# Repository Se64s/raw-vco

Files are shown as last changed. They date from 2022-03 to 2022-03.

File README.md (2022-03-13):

# raw-vco

Eurorack VCO module based in EDU DIY VCO from erica synth and Moritz Klein.

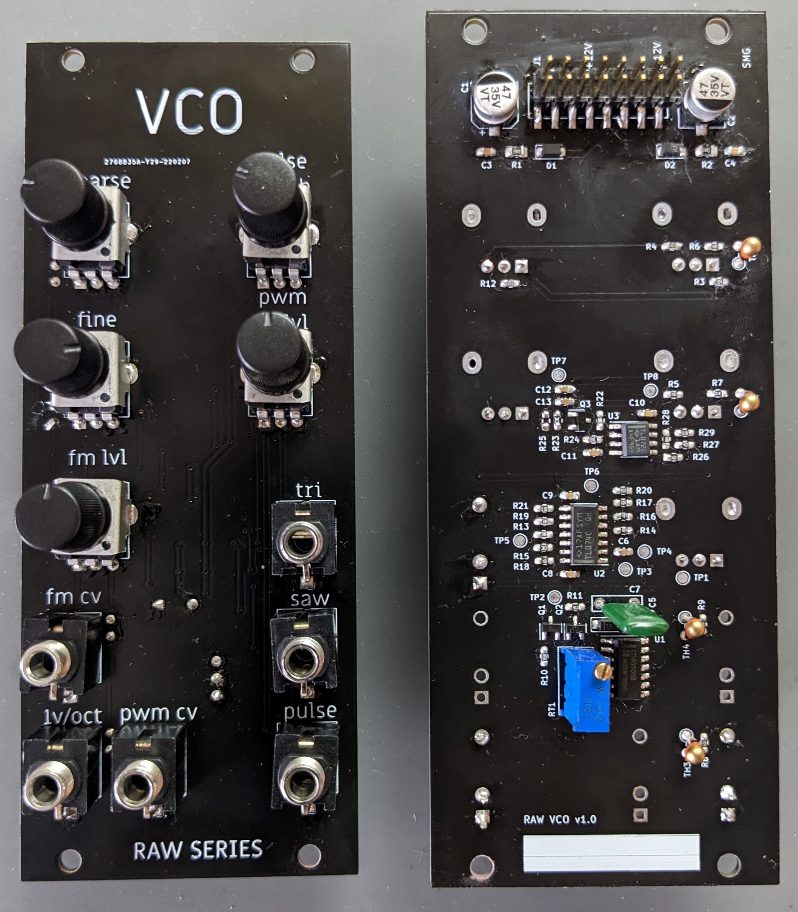
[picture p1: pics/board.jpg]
raw_vco_pcb


# About the project

This is the first module of the series 'RAW'.

The RAW concept is my way to ease access to the modular world, reducing the cost of the modules to the minimum, removing all unnecessary parts without scarify functionality.

In this case, I took the awesome design of Moritz, but I removed the fancy faceplate and I added a saw-triangle converter to have all the basic waveforms.

# Module overview

## Inputs

- lineal fm cv input.
- pwm cv control input.
- 1v/oct control input (good tracking over 5 octaves).

## Outputs

### Triagle
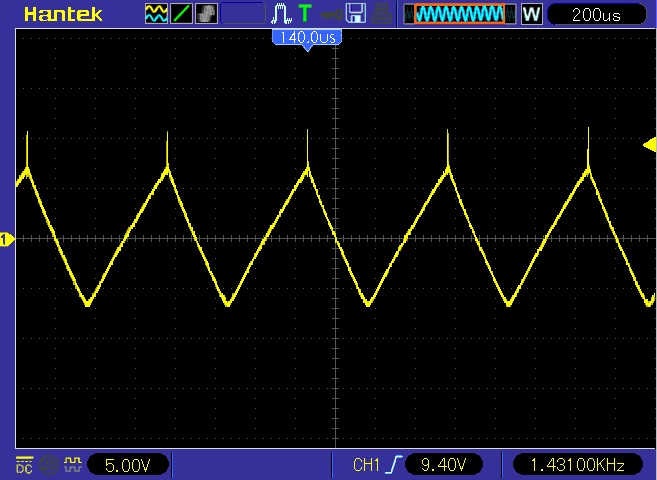
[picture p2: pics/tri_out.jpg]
tri_out


### Saw
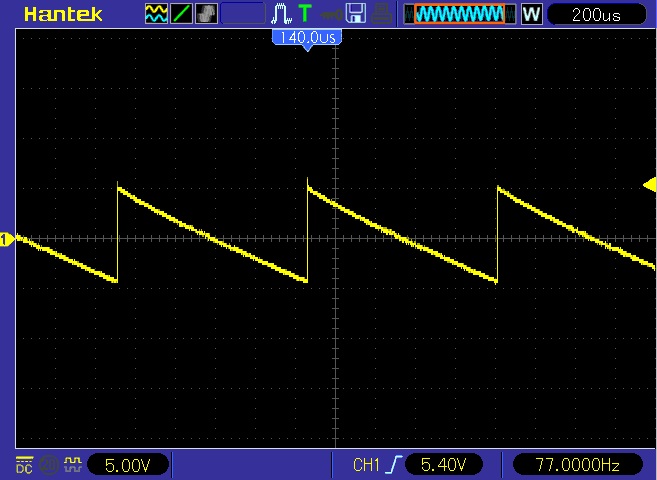
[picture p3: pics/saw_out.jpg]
saw_out


### Square
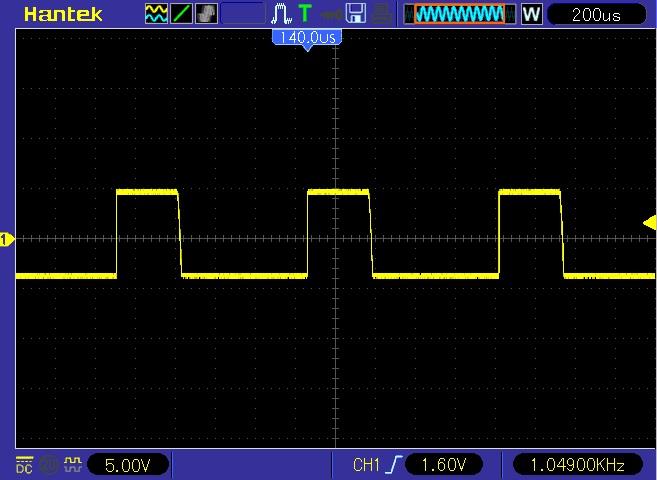
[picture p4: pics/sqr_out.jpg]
sqr_out


# Acknowledgments

All design and guts of this module were done by Moritz Klein so I recommend visiting his awesome videos to get a precise idea of how this module works.

- [mki x es.EDU](https://www.ericasynths.lv/news/mki-x-esedu/)

# Contact

Any feedback is welcome!
- Sebastián Del Moral - sebmorgal@gmail.com

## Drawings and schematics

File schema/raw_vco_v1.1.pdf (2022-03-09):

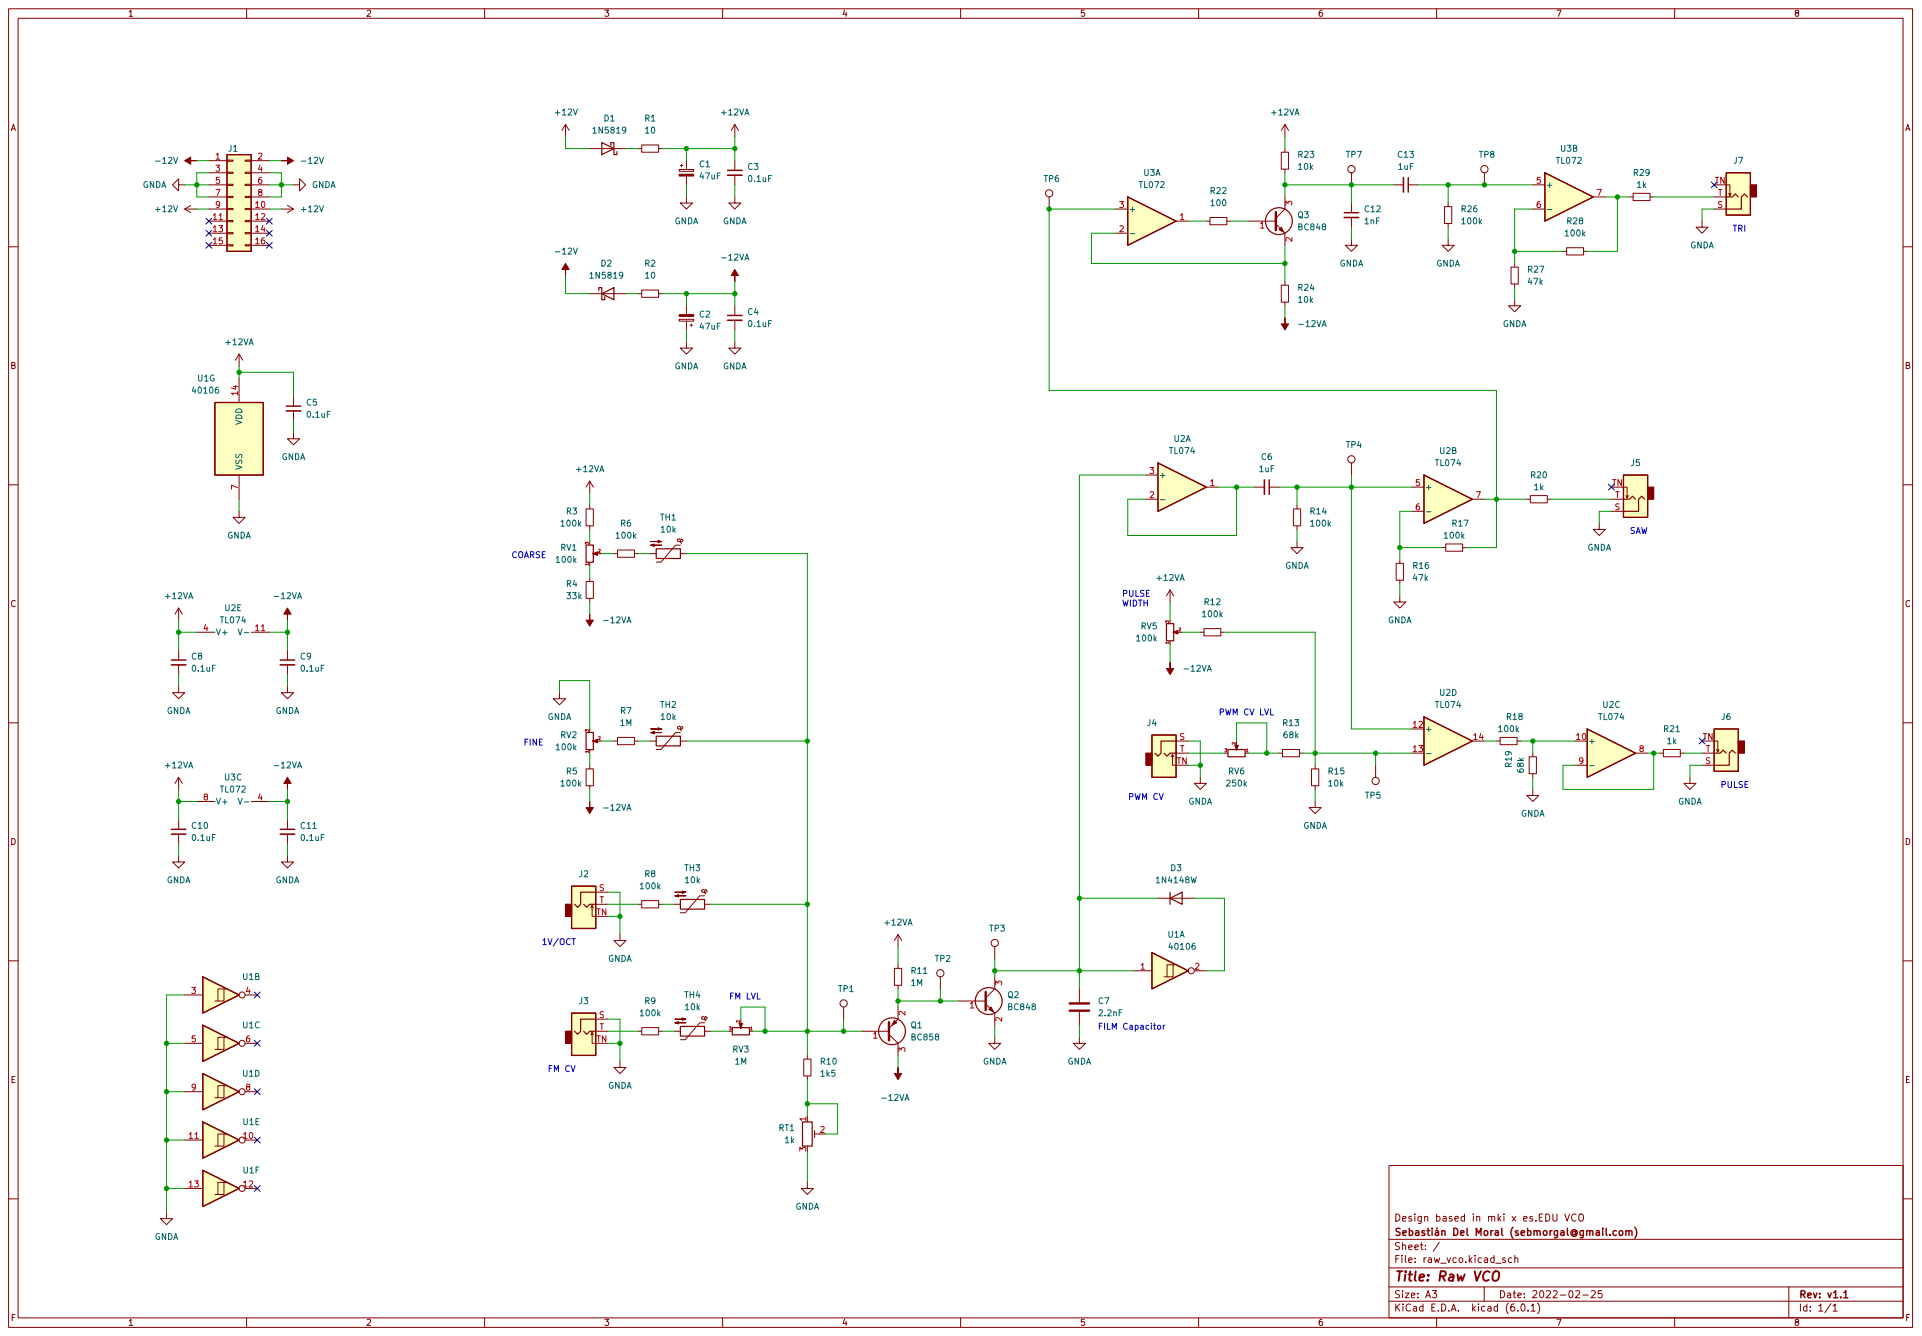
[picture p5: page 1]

PWM CV LVL COARSE

Design based in mki x es.EDU VCO R19 68k

Id: 1/1 Title: Raw VCO

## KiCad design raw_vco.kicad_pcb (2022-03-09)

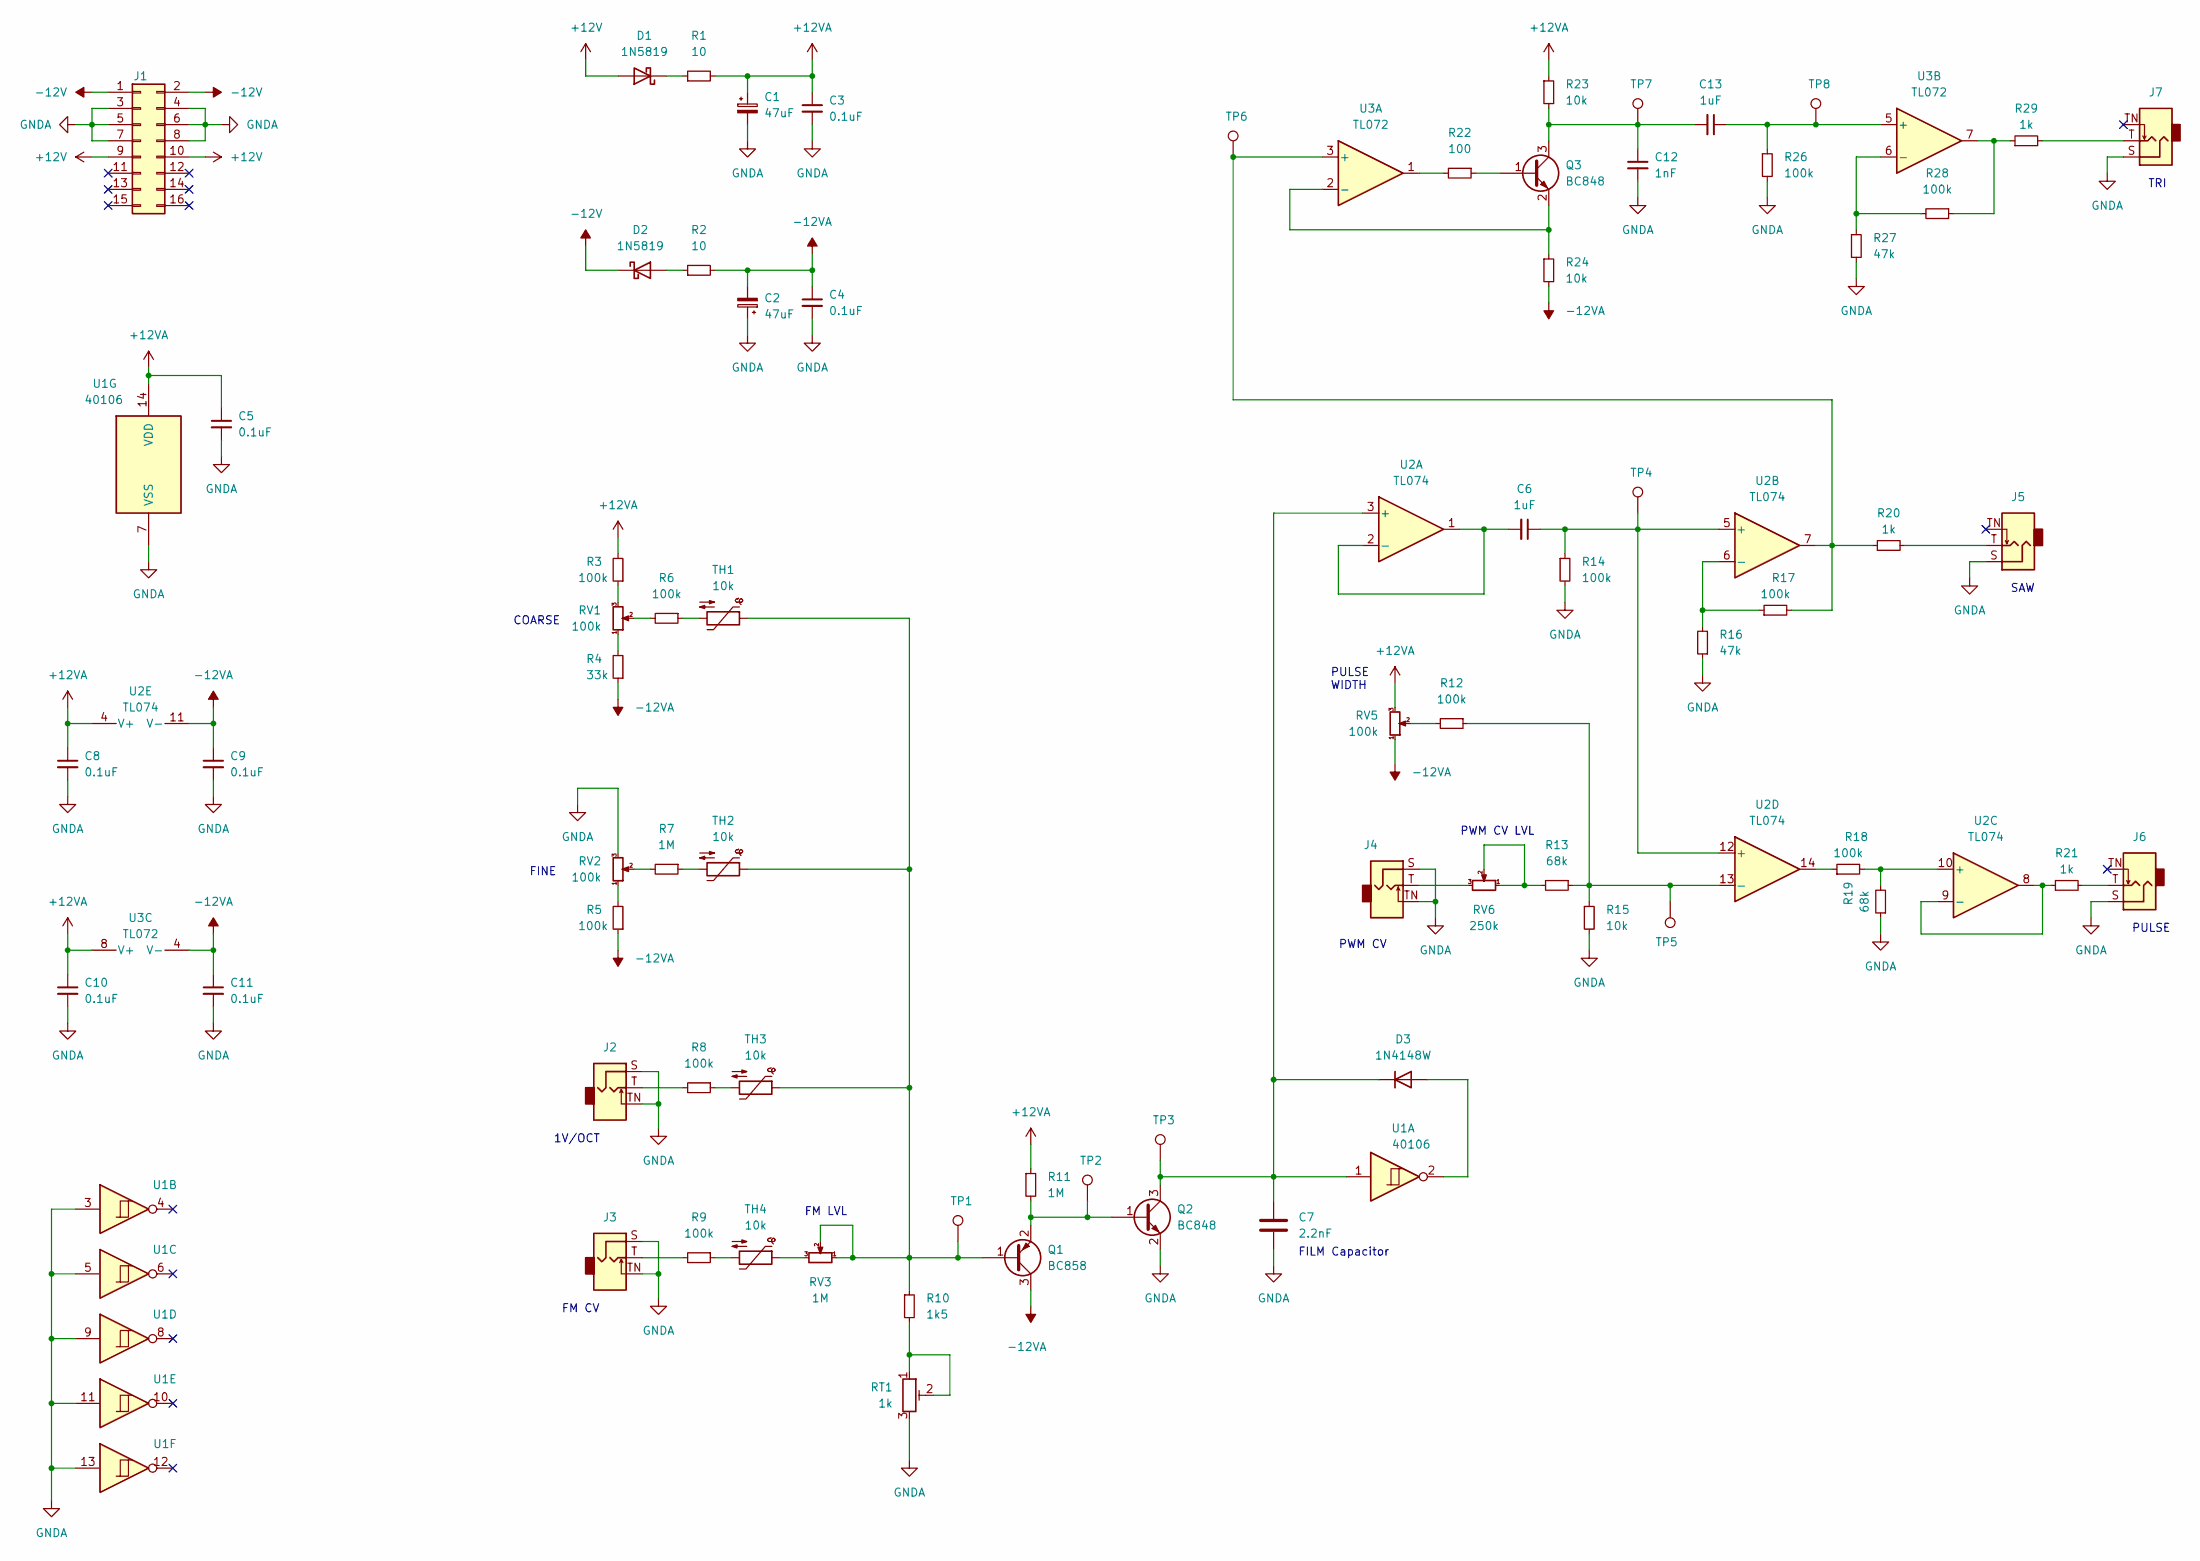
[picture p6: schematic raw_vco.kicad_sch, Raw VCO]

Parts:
C1, C2: 47uF; CP_Elec_6.3x5.4
C3, C4, C5, C8, C9, C10, C11: 0.1uF; C_0603_1608Metric_Pad1.08x0.95mm_HandSolder
C6, C13: 1uF; C_0603_1608Metric_Pad1.08x0.95mm_HandSolder
C7: 2.2nF; C_Rect_L7.0mm_W2.0mm_P5.00mm
C12: 1nF; C_0603_1608Metric_Pad1.08x0.95mm_HandSolder
D1, D2: 1N5819; D_SOD-123
D3: 1N4148W; D_SOD-123
J1: Conn_02x08_Odd_Even; PinHeader_2x08_P2.54mm_Vertical_SMD
J2, J3, J4, J5, J6, J7: AudioJack2_SwitchT; Jack_3.5mm_QingPu_WQP-PJ398SM_Vertical_CircularHoles
Q1: BC858; SOT-23
Q2, Q3: BC848; SOT-23
R1, R2: 10; R_0805_2012Metric_Pad1.20x1.40mm_HandSolder
R3, R5, R6, R8, R9, R12, R14, R17, R18, R26, R28: 100k; R_0603_1608Metric_Pad0.98x0.95mm_HandSolder
R4: 33k; R_0603_1608Metric_Pad0.98x0.95mm_HandSolder
R7, R11: 1M; R_0603_1608Metric_Pad0.98x0.95mm_HandSolder
R10: 1k5; R_0603_1608Metric_Pad0.98x0.95mm_HandSolder
R13, R19: 68k; R_0603_1608Metric_Pad0.98x0.95mm_HandSolder
R15, R23, R24: 10k; R_0603_1608Metric_Pad0.98x0.95mm_HandSolder
R16, R27: 47k; R_0603_1608Metric_Pad0.98x0.95mm_HandSolder
R20, R21, R29: 1k; R_0603_1608Metric_Pad0.98x0.95mm_HandSolder
R22: 100; R_0603_1608Metric_Pad0.98x0.95mm_HandSolder
RT1: 1k; Potentiometer_Bourns_3296W_Vertical
RV1, RV2, RV5: 100k; Potentiometer_Alpha_RD901F-40-00D_Single_Vertical
RV3: 1M; Potentiometer_Alpha_RD901F-40-00D_Single_Vertical
RV6: 250k; Potentiometer_Alpha_RD901F-40-00D_Single_Vertical
TH1, TH2, TH3, TH4: 10k; R_Axial_DIN0204_L3.6mm_D1.6mm_P2.54mm_Vertical
TP1, TP2, TP3, TP4, TP5, TP6, TP7, TP8: TestPoint; TestPoint_Pad_D1.5mm
U1: 40106; SOIC-14_3.9x8.7mm_P1.27mm
U2: TL074; SOIC-14_3.9x8.7mm_P1.27mm
U3: TL072; SOIC-8_3.9x4.9mm_P1.27mm

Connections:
+12V: D1.2 (A), J1.9, J1.10
+12VA: C1.1, C3.1, C5.1, C8.1, C10.1, R1.2, R3.2, R11.1, R23.1, RV5.3, U1.14 (VDD), U2.4 (V+), U3.8 (V+)
-12V: D2.1 (K), J1.1, J1.2
-12VA: C2.2, C4.1, C9.1, C11.1, Q1.3 (C), R2.2, R4.1, R5.1, R24.2, RV5.1, U2.11 (V-), U3.4 (V-)
GNDA: C1.2, C2.1, C3.2, C4.2, C5.2, C7.2, C8.2, C9.2, C10.2, C11.2, C12.2, J1.3, J1.4, J1.5, J1.6, J1.7, J1.8, J2.S, J2.TN, J3.S, J3.TN, J4.S, J4.TN, J5.S, J6.S, J7.S, Q2.2 (E), R14.2, R15.2, R16.1, R19.1, R26.2, R27.2, RT1.3, RV2.3, U1.3, U1.5, U1.7 (VSS), U1.9, U1.11, U1.13
unnamed: C6.1, R14.1, TP4.1, U2.5 (+), U2.12 (+)
unnamed: C6.2, U2.1, U2.2 (-)
unnamed: C7.1, D3.1 (K), Q2.3 (C), TP3.1, U1.1, U2.3 (+)
unnamed: C12.1, C13.2, Q3.3 (C), R23.2, TP7.1
unnamed: C13.1, R26.1, TP8.1, U3.5 (+)
unnamed: D1.1 (K), R1.1
unnamed: D2.2 (A), R2.1
unnamed: D3.2 (A), U1.2
unnamed: J2.T, R8.2
unnamed: J3.T, R9.2
unnamed: J4.T, RV6.3
unnamed: J5.T, R20.2
unnamed: J6.T, R21.2
unnamed: J7.T, R29.2
unnamed: Q1.1 (B), R10.1, RV3.1, RV3.2, TH1.1, TH2.1, TH3.1, TP1.1
unnamed: Q1.2 (E), Q2.1 (B), R11.2, TP2.1
unnamed: Q3.1 (B), R22.1
unnamed: Q3.2 (E), R24.1, U3.2 (-)
unnamed: R3.1, RV1.3
unnamed: R4.2, RV1.1
unnamed: R5.2, RV2.1
unnamed: R6.1, TH1.2
unnamed: R7.1, TH2.2
unnamed: R7.2, RV2.2
unnamed: R8.1, TH3.2
unnamed: R9.1, TH4.2
unnamed: R10.2, RT1.1, RT1.2
unnamed: R12.1, R13.1, R15.1, TP5.1, U2.13 (-)
unnamed: R12.2, RV5.2
unnamed: R13.2, RV6.1, RV6.2
unnamed: R16.2, R17.1, U2.6 (-)
unnamed: R17.2, R20.1, TP6.1, U2.7, U3.3 (+)
unnamed: R18.1, U2.14
unnamed: R18.2, R19.2, U2.10 (+)
unnamed: R21.1, U2.8, U2.9 (-)
unnamed: R22.2, U3.1
unnamed: R27.1, R28.2, U3.6 (-)
unnamed: R28.1, R29.1, U3.7
unnamed: R6.2, RV1.2
unnamed: RV3.3, TH4.1

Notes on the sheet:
FILM Capacitor
PWM CV
TRI
COARSE
PWM CV LVL
FINE
SAW
PULSE
1V/OCT
FM LVL
FM CV
PULSE WIDTH

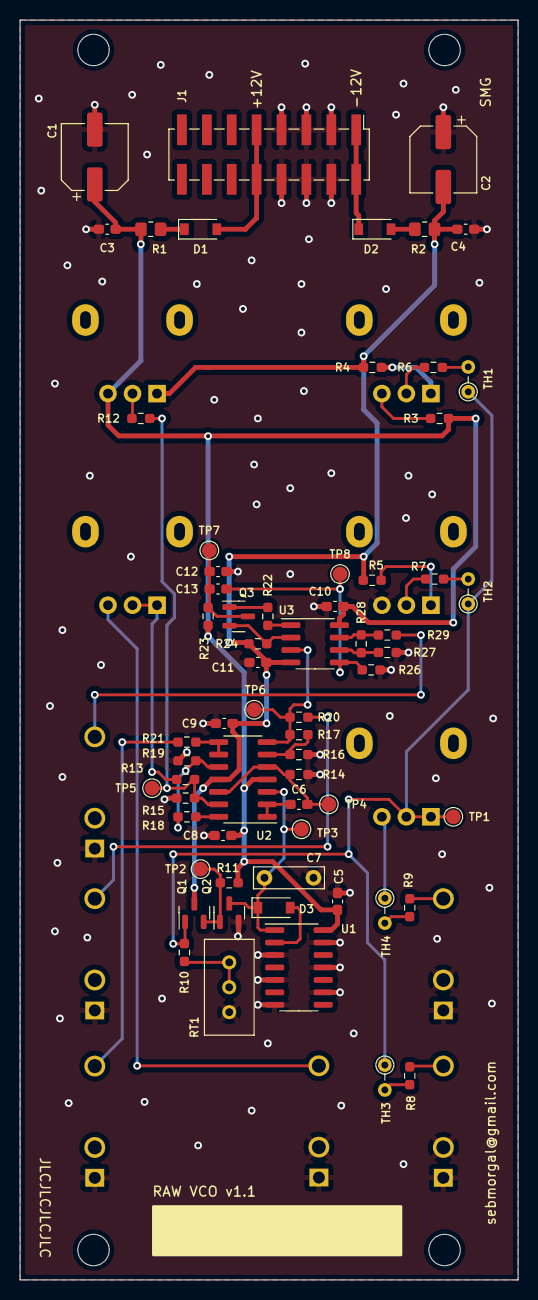
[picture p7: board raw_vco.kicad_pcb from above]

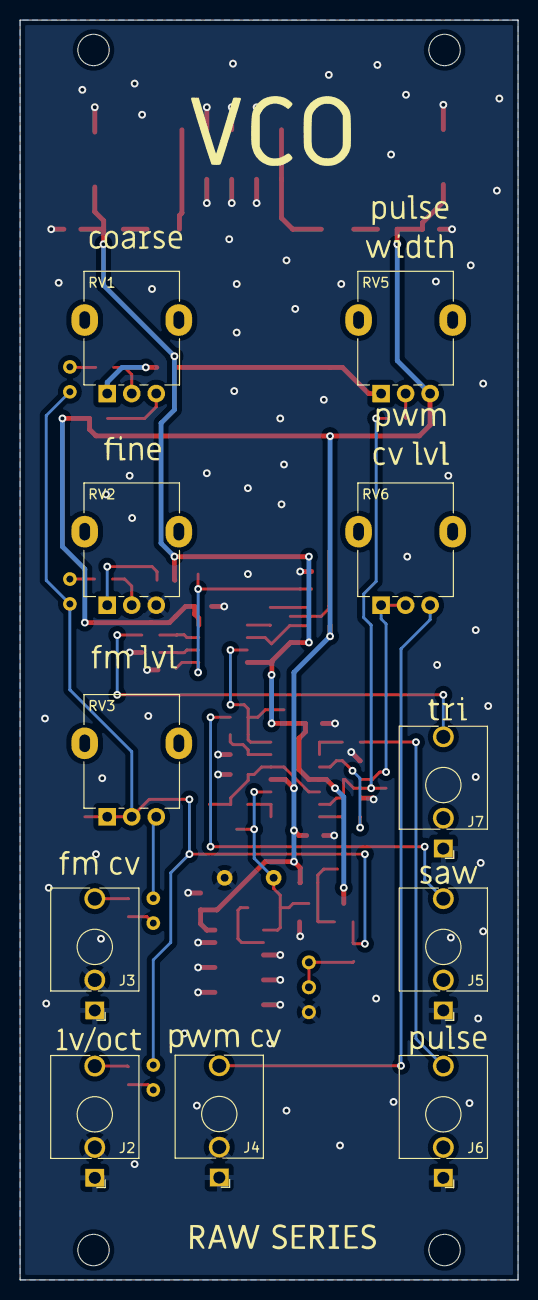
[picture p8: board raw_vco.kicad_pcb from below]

Board: 2 copper layers, 50.8 x 128.5 mm, 75 parts (11 on the bottom side), 45 nets.
